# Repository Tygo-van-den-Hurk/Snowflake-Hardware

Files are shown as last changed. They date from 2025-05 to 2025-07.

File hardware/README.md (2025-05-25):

> This submodule is for generating the hardware of my keyboard.

[< Back to the main README](../README.md)

# Hardware

- [Hardware](#hardware)
  - [Overview](#overview)
  - [Ergogen](#ergogen)
    - [Points](#points)
    - [Adding custom footprints](#adding-custom-footprints)
  - [External Resources](#external-resources)
  - [Components](#components)

## Overview

For the generating the files we need for the hardware we'll be using [ergogen](https://github.com/ergogen/ergogen). [Ergogen](https://github.com/ergogen/ergogen) is a program that allows you to build keyboards from a YAML config file.

## Ergogen

We use ergogen to build the PCBs, outlines, cases, and points for us. I made a nix wrapper to build the results from ergogen see [the contributing guide](../CONTRIBUTING.md) as ergogen does not generate STL files

### Points

So there is one thing I discovered with Ergogen, to have an exact location that is the same on the outlines, cases, and PCBs, it needs to be a point. Points are originally used for key switches, but they work fine for other things. For this reason I added the following points:

```YAML
points:
  zones:
    ...

    # Microcontroller
    microcontroller:
      ...

    # mounting holes
    mounting_hole_top_right:
      ...
    mounting_hole_bottom_right:
      ...
    mounting_hole_bottom_middle:
      ...
    mounting_hole_top_left:
      ...
    mounting_hole_bottom_left:
      ...

    # Nix logo
    nix_logo:
      ...
```

The next step is to create an outline

### Adding custom footprints

There is just one problem: Ergogen does not natively support the pro micro I want to use for my keyboard. So to solve this we have to use footprints. Footprints is a way to extend ergogen's functionality beyond it's native capabilities.

To use footprints we have to use the following structure: there has to be a directory called `footprints` and a file called `config.yaml`. The `config.yaml` is where we'll describe our keyboard to ergogen, and in the `footprints` folder we'll put our missing footprints. Thanks to [@Narkoleptika](https://github.com/Narkoleptika)'s hard work (or who ever he got it from) there is a footprint for the pro micro.

If you need any footprint that this repository is missing, you can find it's JavaScript file, and add it to the `./src/footprints/` directory. There are a lot of footprints you can use. Just make sure it's well tested, because a bad footprint could technically destroy your microcontroller.

## External Resources

- [The ergogen docs](https://docs.ergogen.xyz/) for any questions about how ergogen works.
- [Web-based deployments](https://ergogen.ceoloide.com/) for getting a visual impression of what the keys look like.
- [The ergogen v4 guid I used](https://flatfootfox.com/ergogen-introduction/) for a step by step tutorial.
- [A website that converts JS CAD to STL](https://neorama.de/). This is nice as a JS CAD file isn't useful on its own. Though the flake does provide the openJScad package to convert them manually.

## Components

Here are the components I used for my keyboard:

- Choc key switches;
- a `pro micro` microcontroller;
- my self made PCB;
- diodes.

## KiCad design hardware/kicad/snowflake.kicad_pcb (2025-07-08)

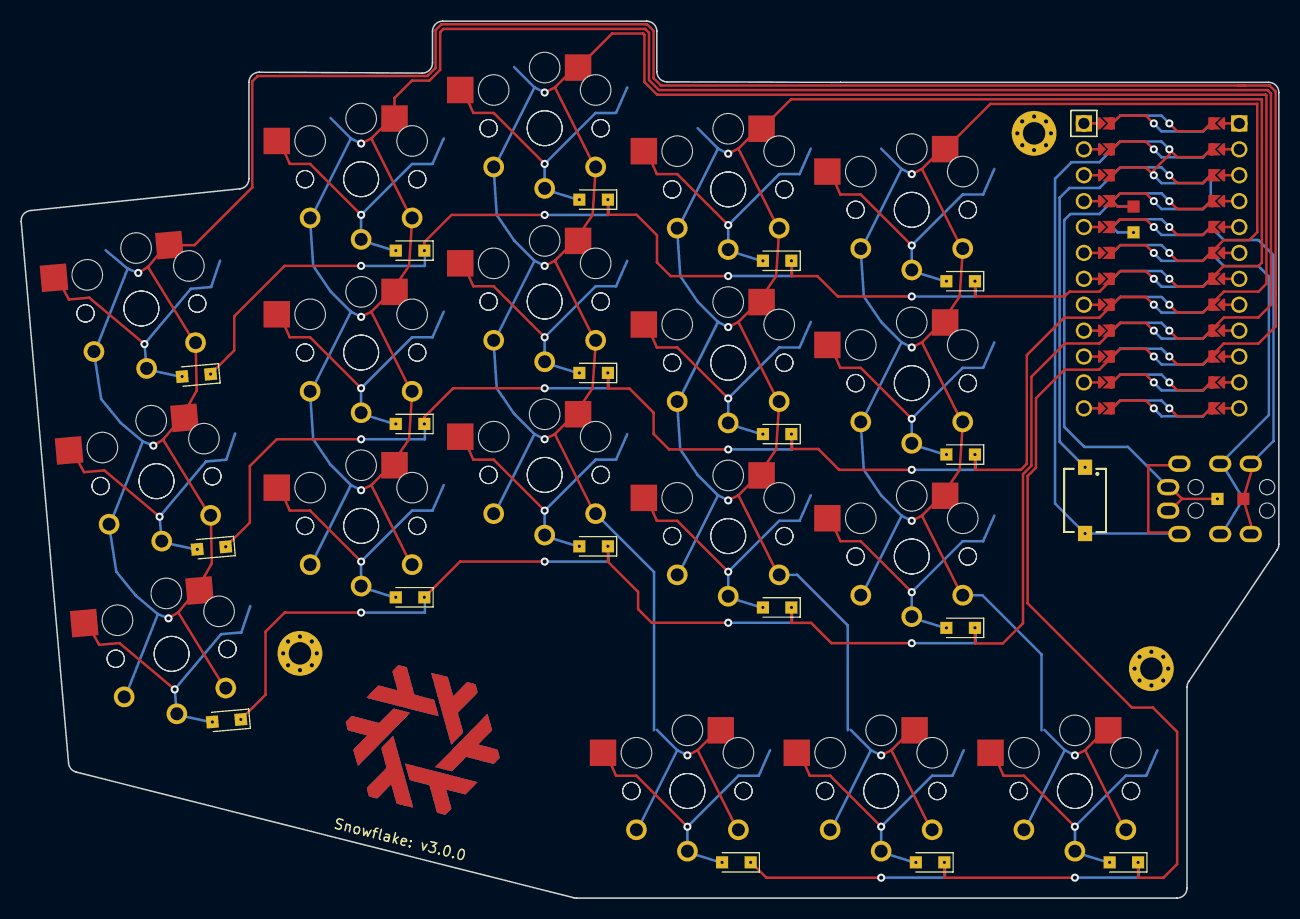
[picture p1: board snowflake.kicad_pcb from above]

Board: 2 copper layers, 123.3 x 86.0 mm, 62 parts (0 on the bottom side), 33 nets.

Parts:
D1, D2, D3, D4, D5, D6, D7, D8, D9, D10, D11, D12, D13, D14, D15, D16, D17, D18: Nexperia_CFP3_SOD-123W
MCU1: ProMicro
S1: 434121025816
S2, S3, S4, S5, S6, S7, S8, S9, S10, S11, S12, S13, S14, S15, S16, S17, S18, S19, S20, S21, S22, S23, S24, S25, S26, S27, S28, S29, S30, S31, S32, S33, S34, S35, S36, S37: PG1350
TRRS1: TRRS-PJ-320A-dual
_1, _2, _3: MountingHole_2.2mm_M2_Pad_Via
threeWayJumper1, threeWayJumper2: Jumper; Jumper_1TH_2SMD

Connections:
GND: MCU1.2, MCU1.21, MCU1.22, S1.2, TRRS1.2, threeWayJumper1.2
P2: MCU1.20, TRRS1.4, threeWayJumper2.2
P3: MCU1.19, TRRS1.3, threeWayJumper2.3
P4: D3.1, D6.1, D9.1, D12.1, D15.1, MCU1.18
P5: D2.1, D5.1, D8.1, D11.1, D14.1, MCU1.17
P6: D1.1, D4.1, D7.1, D10.1, D13.1, MCU1.16
P7: D16.1, D17.1, D18.1, MCU1.15
P14: MCU1.10, S2.1, S3.1, S4.1, S20.1, S21.1, S22.1
P15: MCU1.9, S5.1, S6.1, S7.1, S23.1, S24.1, S25.1
P18: MCU1.8, S8.1, S9.1, S10.1, S17.1, S26.1, S27.1, S28.1, S35.1
P19: MCU1.7, S11.1, S12.1, S13.1, S18.1, S29.1, S30.1, S31.1, S36.1
P20: MCU1.6, S14.1, S15.1, S16.1, S19.1, S32.1, S33.1, S34.1, S37.1
P21: MCU1.5, threeWayJumper1.1
RST: MCU1.3, S1.1
VCC: MCU1.4, TRRS1.1, threeWayJumper1.3, threeWayJumper2.1
matrix_index_bottom: D10.2, S11.2, S29.2
matrix_index_home: D11.2, S12.2, S30.2
matrix_index_top: D12.2, S13.2, S31.2
matrix_inner_bottom: D13.2, S14.2, S32.2
matrix_inner_home: D14.2, S15.2, S33.2
matrix_inner_top: D15.2, S16.2, S34.2
matrix_middle_bottom: D7.2, S8.2, S26.2
matrix_middle_home: D8.2, S9.2, S27.2
matrix_middle_top: D9.2, S10.2, S28.2
matrix_pinky_bottom: D1.2, S2.2, S20.2
matrix_pinky_home: D2.2, S3.2, S21.2
matrix_pinky_top: D3.2, S4.2, S22.2
matrix_ring_bottom: D4.2, S5.2, S23.2
matrix_ring_home: D5.2, S6.2, S24.2
matrix_ring_top: D6.2, S7.2, S25.2
thumbfan_far_thumb: D18.2, S19.2, S37.2
thumbfan_home_thumb: D17.2, S18.2, S36.2
thumbfan_near_thumb: D16.2, S17.2, S35.2

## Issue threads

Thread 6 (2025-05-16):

Make nix build autowire the KICAD PCB

Tygo-van-den-Hurk, 2025-05-16:
Right now as of writing the PCBs produced by ergogen don't wire themselves. I think it'd be a nice addition to make this using [freerouting](https://github.com/freerouting/freerouting) or something similar.

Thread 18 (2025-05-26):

Nix Logo not alligned

Tygo-van-den-Hurk, 2025-05-26:
The nix logo is not aligned in the center of the keyboard cause of the mounting hole.

Tygo-van-den-Hurk, 2025-05-26:
You might be able to resolve this by screwing it in using the same color screws as the PCB. Then it will look centered, and then it would look off if it was moved.

Closed 2025-05-26.

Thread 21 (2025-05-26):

Make the image on the main README respect light and dark mode.

Tygo-van-den-Hurk, 2025-05-26:
So currently the the SVG only works well on darkmode but not light mode as the holes are white just like the PCB itself.

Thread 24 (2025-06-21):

Make TTRS connector closer to the edge

Tygo-van-den-Hurk, 2025-06-21:
I build the keyboard and ran into issues. The TTRS connector was too far from the edge and the plug won't go in because of it.

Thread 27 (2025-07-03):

Make STLs produce both case halves

Tygo-van-den-Hurk, 2025-07-03:
So as of writing when you create the cases, you’ll only get the left half as officially you’re only making 1 half that is reversible. Thus a right half must also be produced.

I’ve looked into some options:

- admesh
- meshconv
- openscad

Only the last one being in nix pkgs.

Closed 2025-07-08.

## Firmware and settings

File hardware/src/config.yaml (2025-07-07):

# //yaml-language-server: $schema=https://raw.githubusercontent.com/ergogen/ergogen/daaef0af7912c7e011ec424421c36210969e3fae/meta/schema.json
#
# This file is a config file from which `ergogen` will generate the PBCs, SVGs etc. I need those to build my keyboard.
# To not run into issues use ergogen v4.0.2 just like me. (See nix flake for up to date version)
#
# ~~~~~~~~~~~~~~~~~~~~~~~~~~~~~~~~~~~~~~~~~~~~~~~~~~~~~~~~~~~~~~~~~~~~~~~~~~~~~~~~~~~~~~~~~~~~~~~~~~~~~~~~~~~~~~~~~~~ #

X-common:
  keyboard:
    name: &silk-text "Snowflake: v3.0.0"
    version: &version "v3.0.0"
    creator: &creator '"Tygo van den Hurk"'
  placement:
    - &any_place_where_a_key_is /(?:thumbfan|matrix)_.*/gi
    - &main_key_matrix_except_top /^matrix_(?!.*top).*$/gi
    - &main_key_matrix_except_bottom /^matrix_(?!.*bottom).*$/gi
    - &any_key_expect_the_outer_ones /(?:^matrix_(?!pinky)|^thumbfan_(?!.*near)).*$/gi
  cases:
    - &mounting-holes-extrude 4
    - &wall-height 4
  sides:
    - &back-side B
    - &frond-side F
# ~~~~~~~~~~~~~~~~~~~~~~~~~~~~~~~~~~~~~~~~~~~~~~~~~~~~~~~ Meta ~~~~~~~~~~~~~~~~~~~~~~~~~~~~~~~~~~~~~~~~~~~~~~~~~~~~~~ #

meta:
  version: *version
  author: *creator

# ~~~~~~~~~~~~~~~~~~~~~~~~~~~~~~~~~~~~~~~~~~~~~~~~~~~~~~ Units ~~~~~~~~~~~~~~~~~~~~~~~~~~~~~~~~~~~~~~~~~~~~~~~~~~~~~~ #

units:
  # Proxy Spacing Variables
  kx: cx
  ky: cy
  # Padding Variables
  px: cx + 4
  py: cy + 4
  # Microcontroller sizes
  Mx: 19
  My: 32
  # TRRS connector sizes
  TRRSx: 13.0
  TRRSy: 10.0
  #
  case_padding: 2.00 # The thickness of the walls around the case.
  pcb_padding: 2.00 # The space between the keys and the edge of the PCB.
  extra_trace: 1.00 # The extra amount of padding 1 extra trace requires.

  # Directions (functions that take care of whether something is positive or negative)
  direction_T: 1.00 # Top
  direction_R: 1.00 # Right
  direction_B: -1.00 # Bottom
  direction_L: -1.00 # Left

  #
  mounting_hole_outer_radius: 2.5
  mounting_hole_outer_diameter: 2*mounting_hole_outer_radius
  mounting_hole_inner_radius: 1.5
  mounting_hole_inner_diameter: 2*mounting_hole_inner_radius

# ~~~~~~~~~~~~~~~~~~~~~~~~~~~~~~~~~~~~~~~~~~~~~~~~~~~~~~ Points ~~~~~~~~~~~~~~~~~~~~~~~~~~~~~~~~~~~~~~~~~~~~~~~~~~~~~ #

points:
  rotate: 0
  zones:
    #` Main key cluster
    matrix:
      key:
        padding: 1ky
        spread: 1kx
      anchor:
        rotate: 5
        shift: [100, -100]
      columns:
        pinky.key:
          col_net: P14
        ring.key:
          splay: -5
          origin: [-12, -19]
          stagger: 12
          col_net: P15
        middle.key:
          stagger: 5
          col_net: &middle-col-net P18
        index.key:
          stagger: -6
          col_net: &index-col-net P19
        inner.key:
          stagger: -2
          col_net: &outer-col-net P20
      rows:
        bottom:
          row_net: P6
        home:
          row_net: P5
        top:
          row_net: P4

    #` Thumb cluster
    thumbfan:
      anchor:
        ref: matrix_inner_bottom
        shift: [-22, -23]
      columns:
        near.key:
          col_net: *middle-col-net
        home.key:
          col_net: *index-col-net
        far.key:
          col_net: *outer-col-net
          width: 1.5kx
      rows:
        thumb:
          row_net: P7

    #` Micro Controller
    microcontroller:
      anchor:
        ref: matrix_index_top
        shift:
          - 3*(kx/2) + (Mx/2) + 6
          - 1*(ky/2) - (My/2)
      columns.x.rows.y.bind: [0, 0]

    #` mounting holes
    mounting_hole_top_right:
      anchor:
        ref: matrix_inner_top
        shift: [(kx/2) + 3, 7.5]
      columns.x.rows.y.bind: [0, 0]
    mounting_hole_bottom_right:
      anchor:
        ref: thumbfan_far_thumb
        shift: [direction_R*(7.5), direction_T*(12)]
      columns.x.rows.y.bind: [0, 0]
    mounting_hole_bottom_left:
      anchor:
        ref: matrix_ring_bottom
        shift: [-6, -12.5]
      columns.x.rows.y.bind: [0, 0]

    #` Nix logo
    nix_logo:
      anchor:
        ref: matrix_ring_bottom
        shift: [6, -21]
      columns.x.rows.y.bind: [0, 0]

    #` TRRS connector
    trrs:
      columns.x.rows.y.bind: [0, 0]
      anchor:
        ref: microcontroller_x_y
        shift:
          - direction_R*( Mx/2 - TRRSx/2 + case_padding)
          - direction_B*( My/2 + 6.8500 )
# ~~~~~~~~~~~~~~~~~~~~~~~~~~~~~~~~~~~~~~~~~~~~~~~~~~~~~ Outlines ~~~~~~~~~~~~~~~~~~~~~~~~~~~~~~~~~~~~~~~~~~~~~~~~~~~~ #
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

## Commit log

2025-05-25 Redesigned the keyboard fixing a lot of the issues
    So there were several issues with the keyboard I decided to address.
    Those being:
    - there was a short circuit between VCC and data. This is why any
    version before this one should not be considered. This was in relation
    to the TRRS connector that was invalidly configured.
    - removed the longly outer pinky key as I don't think it will serve any
    function.
    - Added non-hot swap capabilities to the keyboard. This means that if
    the keys have a tendency to fall out for some reason I have the option
    to solder them without creating a new version.
    - Removed superfluous mounting holes to save space and as I can always
    add more in future rev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
    [snowflake.kicad_pcb]
2025-05-26 Wired the keyboard
    Wired the keyboard based on the previous changes.
    [production.kicad_pcb, snowflake.kicad_pcb]
2025-05-26 Start to ignore tar files
    This is as these are archive files that can be easily produced, but also
    they are in binary format and thus not easy to track and update. Thus
    they are better left outside of the repository.
2025-06-26 fix: TRRS connector being to close to the edge (#25)
    some TRRS connectors with big husles would get stuck on the edge and would
    not be able to able to go in all the way. This commit resolves that issue.
    closes #24
    [snowflake.kicad_pcb]
2025-07-07 feat!: added a 3 way jumpers (#28)
    So while building the firmware for version 2, I found that I could not
    easily build the firmware deterministically as a write to the EPROM is
    required the first time you flash the firmware. It would be nice to
    have a hardware option to decide what side it is. We solder anything
    into one of two possible configurations anyways, thus this does not
    make the PCB less flexible.
    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
    [snowflake.kicad_pcb]
2025-07-08 feat: made the derivation output both halves of the case
    Before this only the left half was outputted. Now it renders the left half
    after which it mirrors it, and outputs that. Normally you could just find a
    website and make that flip it for you, now that is being done in nix.
    Closes #27: "Make STLs produce both case halves"
2025-07-08 fix: saw a single wire that was not wired up
    There was a missing connection between two keys the PCB would not have worked
    without this fix.
    [snowflake.kicad_pcb]
2025-07-08 feat: add multiple output types
    Now you get 5 output types. These being: binary-stl, ascii-stl, dxf, off, vrml.
2025-07-09 fix: derivation naming
    Almost all were named "pcb", when they were something else.
    Closes #34: "rename derivations to what they produce instead of all being PCB".
